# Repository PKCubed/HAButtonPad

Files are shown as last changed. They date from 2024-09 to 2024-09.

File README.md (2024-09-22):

# HAButtonPad
A board of buttons for Home Assistant

## Features I Want to Add
- Unlimitted number of switches and scenes
- Display switch names on screen when holding down the button (when holding down button, don't register it as a press)

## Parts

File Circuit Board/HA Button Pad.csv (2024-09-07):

# | Reference | Qty | Value | Footprint | DNP
1 | C1, C2, C3, C4, C5, C6, C7, C8 | 8 | C | Capacitor_SMD:C_0805_2012Metric
2 | D1, D2, D3, D4, D5, D6 | 6 | WS2812B | LED_SMD:LED_WS2812B_PLCC4_5.0x5.0mm_P3.2mm
3 | D7 | 1 | Power LED | LED_SMD:LED_0603_1608Metric
4 | D8, D9, D10, D11, D12 | 5 | D_Zener | Diode_SMD:D_0603_1608Metric
5 | DS1 | 1 | Character LCD | Display:WC1602A
6 | H1, H2, H3, H4 | 4 | MountingHole_Pad | MountingHole:MountingHole_2.5mm_Pad
7 | J1 | 1 | Barrel_Jack | Connector_BarrelJack:BarrelJack_CLIFF_FC681465S_SMT_Horizontal
8 | JP1 | 1 | Programming Jumper | Connector_PinHeader_2.54mm:PinHeader_1x02_P2.54mm_Vertical
9 | JP2 | 1 | USB Power Jumper | Connector_PinHeader_2.54mm:PinHeader_1x02_P2.54mm_Vertical
10 | JP3 | 1 | Run Program Jumper | Connector_PinHeader_2.54mm:PinHeader_1x02_P2.54mm_Vertical
11 | P1 | 1 | USB C Connector | Connector_USB:USB_C_Receptacle_GCT_USB4110
12 | Q1 | 1 | PN2222A | Package_TO_SOT_THT:TO-92_Inline
13 | R1 | 1 | Power LED Resistor | Resistor_SMD:R_0603_1608Metric
14 | R2 | 1 | SDA Pullup | Resistor_SMD:R_0603_1608Metric
15 | R3 | 1 | SCL Pullup | Resistor_SMD:R_0603_1608Metric
16 | R4 | 1 | R | Resistor_SMD:R_0603_1608Metric
17 | RV1 | 1 | Display Contrast | Potentiometer_THT:Potentiometer_ACP_CA6-H2,5_Horizontal
18 | SW1 | 1 | Button 1 | Button_Switch_THT:SW_PUSH-12mm
19 | SW2 | 1 | Button 2 | Button_Switch_THT:SW_PUSH-12mm
20 | SW3 | 1 | Button 3 | Button_Switch_THT:SW_PUSH-12mm
21 | SW4 | 1 | Button 4 | Button_Switch_THT:SW_PUSH-12mm
22 | SW5 | 1 | Bank Up | Button_Switch_THT:SW_PUSH-12mm
23 | SW6 | 1 | Bank Down | Button_Switch_THT:SW_PUSH-12mm
24 | SW7 | 1 | Program Button | Button_Switch_THT:SW_PUSH_6mm
25 | U1 | 1 | WT32-ETH01 | DevBoards:WT32-ETH01
26 | U3 | 1 | CP2102N USB TTL Converter | Package_DFN_QFN:QFN-28-1EP_5x5mm_P0.5mm_EP3.1x3.1mm
27 | U4 | 1 | Char LCD I2C Expander | Package_SO:SSOP-20_4.4x6.5mm_P0.65mm
28 | U5 | 1 | Button I2C Expander | Package_SO:SSOP-20_4.4x6.5mm_P0.65mm

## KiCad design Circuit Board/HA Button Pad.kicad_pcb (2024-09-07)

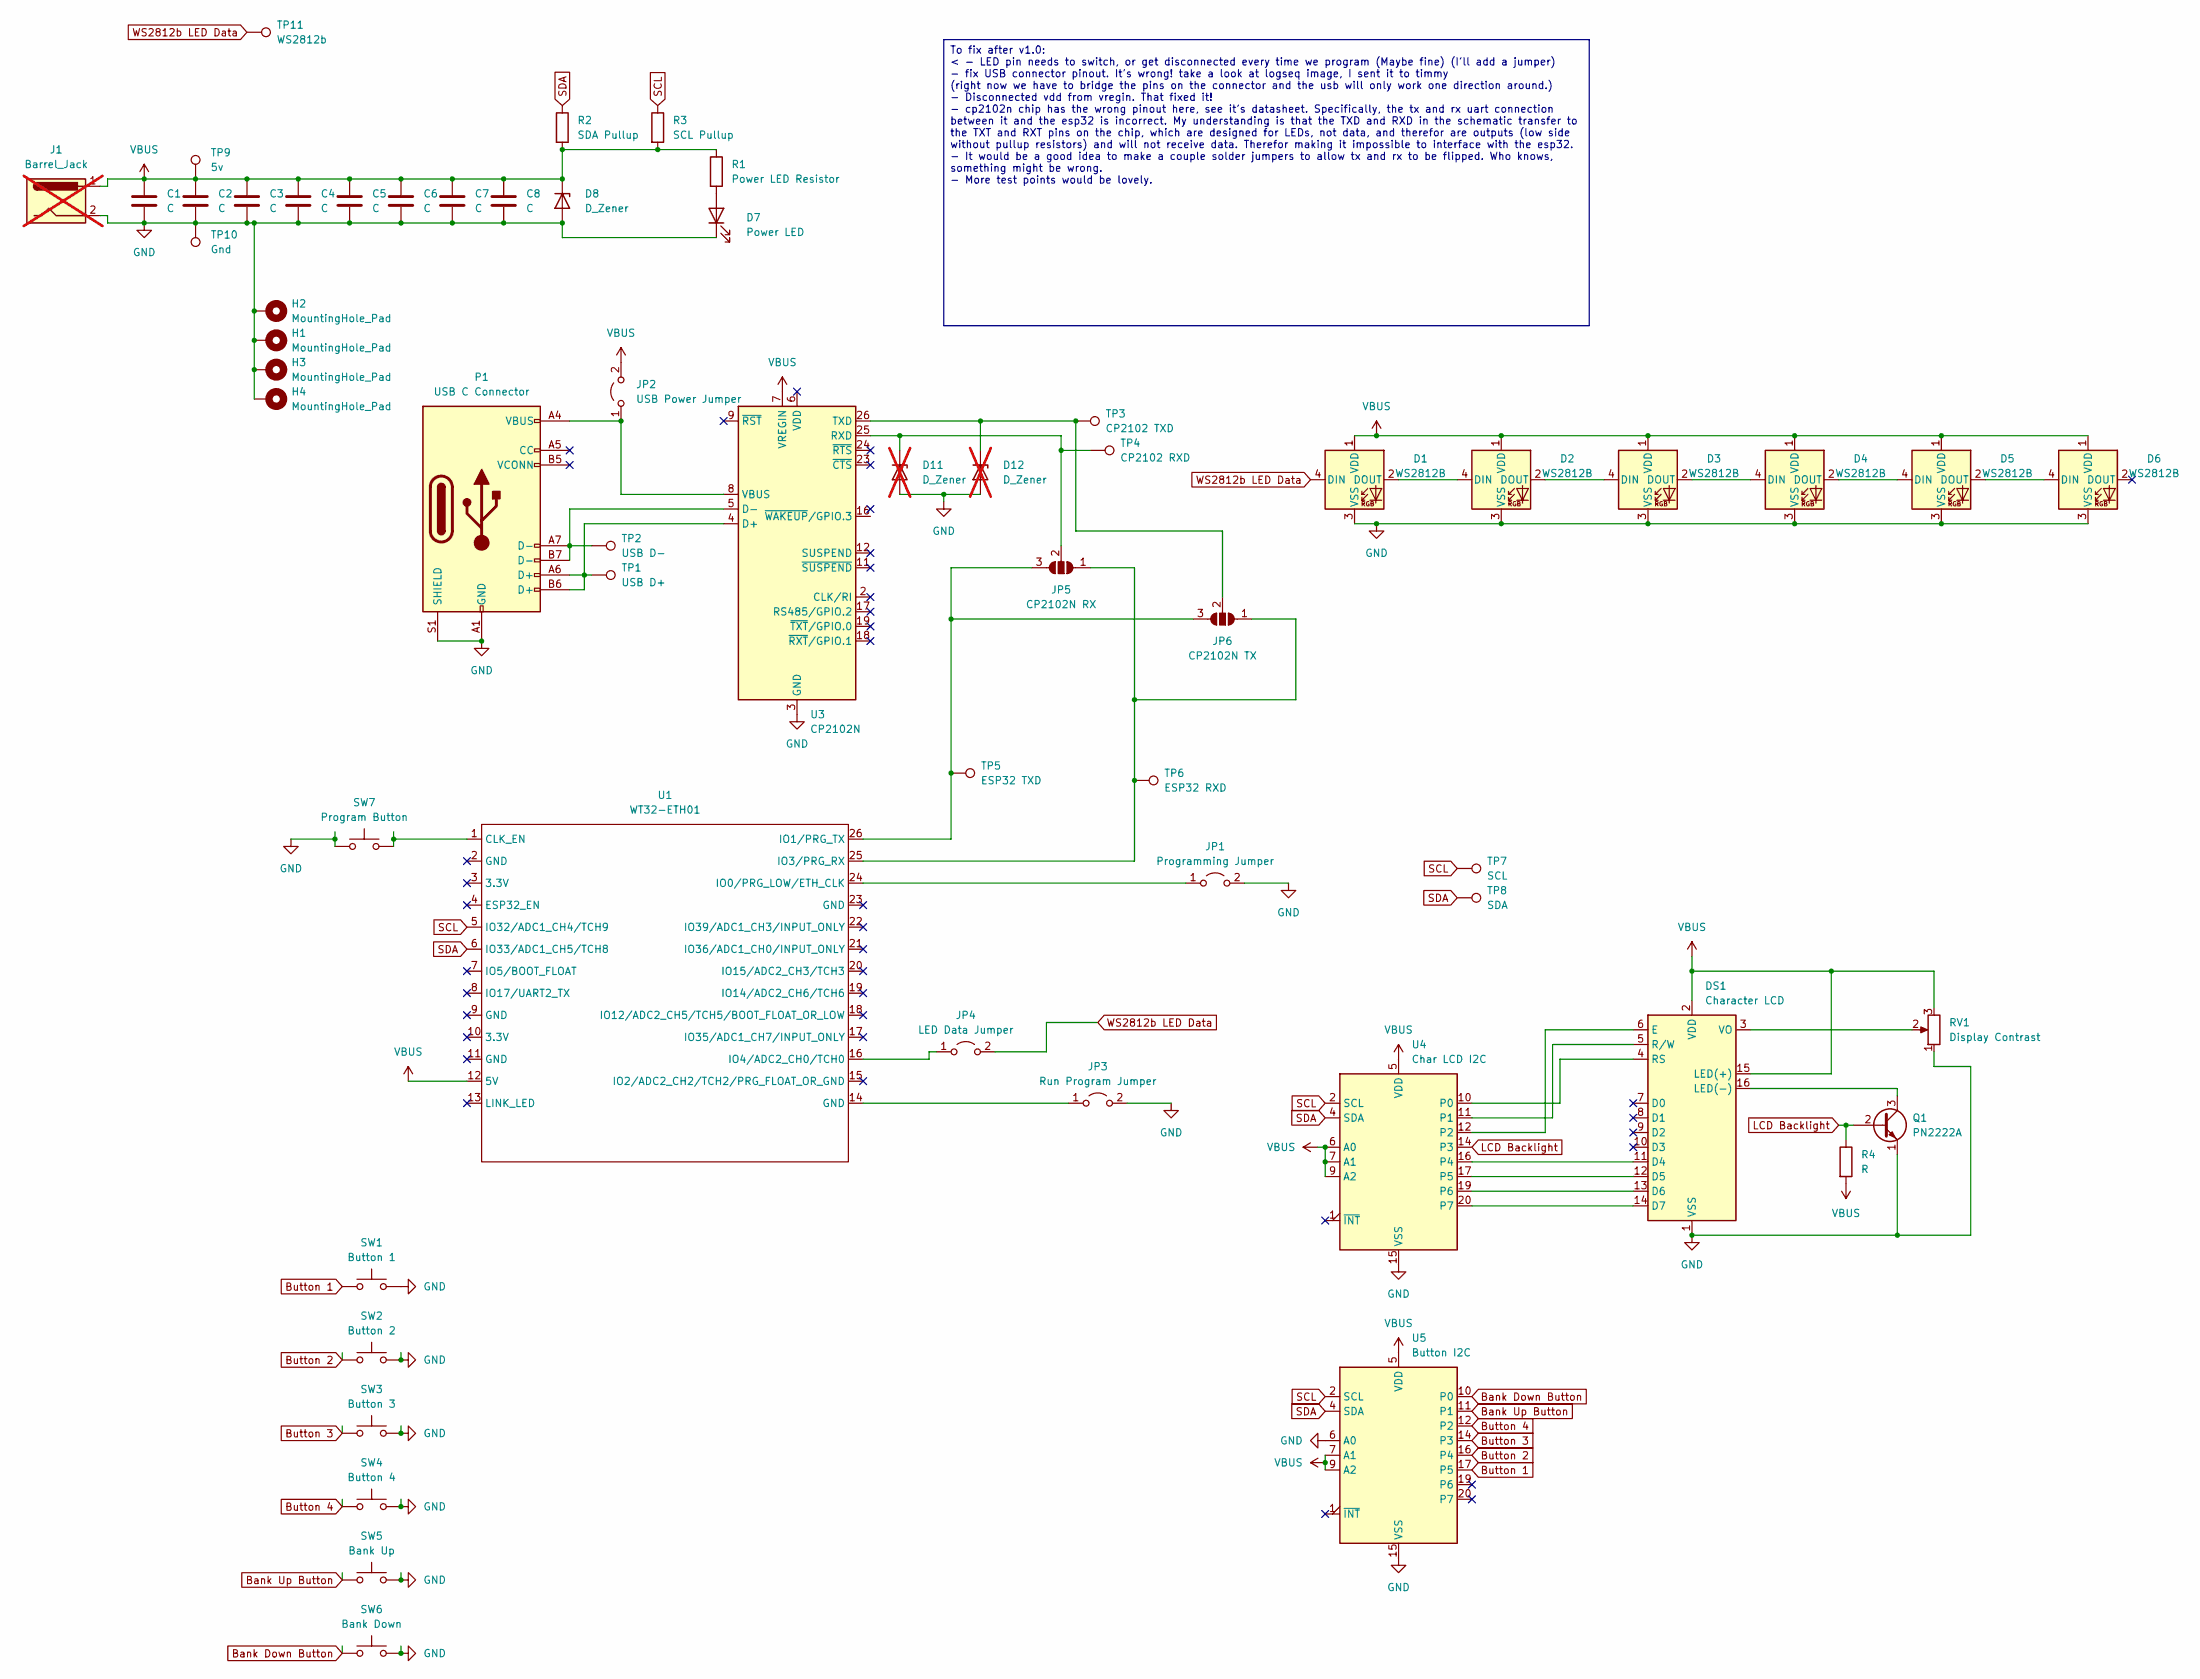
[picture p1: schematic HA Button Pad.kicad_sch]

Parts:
C1, C2, C3, C4, C5, C6, C7, C8: C; CAPC340180_88N_KEM
D1, D2, D3, D4, D5, D6: WS2812B; LED_WS2812B_PLCC4_5.0x5.0mm_P3.2mm
D7: Power LED; LED_0603_1608Metric
D8: D_Zener; SOD923_DIO
D11, D12: D_Zener; SOD923_DIO; not fitted
DS1: Character LCD; WC1602A
H1, H2, H3, H4: MountingHole_Pad; MountingHole_2.5mm_Pad
J1: Barrel_Jack; BarrelJack_CLIFF_FC681465S_SMT_Horizontal; not fitted
JP1: Programming Jumper; PinHeader_1x02_P2.54mm_Vertical
JP2: USB Power Jumper; PinHeader_1x02_P2.54mm_Vertical
JP3: Run Program Jumper; PinHeader_1x02_P2.54mm_Vertical
JP4: LED Data Jumper; PinHeader_1x02_P2.54mm_Vertical
JP5: CP2102N RX; SolderJumper-3_P2.0mm_Open_TrianglePad1.0x1.5mm_NumberLabels
JP6: CP2102N TX; SolderJumper-3_P2.0mm_Open_TrianglePad1.0x1.5mm_NumberLabels
P1: USB C Connector; USB_C_Receptacle_GCT_USB4110
Q1: PN2222A; TO-92_Inline
R1: Power LED Resistor; R_0603_1608Metric
R2: SDA Pullup; R_0603_1608Metric
R3: SCL Pullup; R_0603_1608Metric
R4: R; R_0603_1608Metric
RV1: Display Contrast; POT_3362P
SW1: Button 1; SW_PUSH-12mm
SW2: Button 2; SW_PUSH-12mm
SW3: Button 3; SW_PUSH-12mm
SW4: Button 4; SW_PUSH-12mm
SW5: Bank Up; SW_PUSH-12mm
SW6: Bank Down; SW_PUSH-12mm
SW7: Program Button; SW_PUSH_6mm
TP1: USB D+; TestPoint_Pad_D1.0mm
TP2: USB D-; TestPoint_Pad_D1.0mm
TP3: CP2102 TXD; TestPoint_Pad_D1.0mm
TP4: CP2102 RXD; TestPoint_Pad_D1.0mm
TP5: ESP32 TXD; TestPoint_Pad_D1.0mm
TP6: ESP32 RXD; TestPoint_Pad_D1.0mm
TP7: SCL; TestPoint_Pad_D1.0mm
TP8: SDA; TestPoint_Pad_D1.0mm
TP9: 5v; TestPoint_Pad_D1.0mm
TP10: Gnd; TestPoint_Pad_D1.0mm
TP11: WS2812b; TestPoint_Pad_D1.0mm
U1: WT32-ETH01
U3: CP2102N; QFN-28-1EP_5x5mm_P0.5mm_EP3.1x3.1mm
U4: Char LCD I2C; SSOP-20_4.4x6.5mm_P0.65mm
U5: Button I2C; SSOP-20_4.4x6.5mm_P0.65mm

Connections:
Bank Down Button: SW6.1, U5.10 (P0)
Bank Up Button: SW5.1, U5.11 (P1)
Button 1: SW1.1, U5.17 (P5)
Button 2: SW2.1, U5.16 (P4)
Button 3: SW3.1, U5.14 (P3)
Button 4: SW4.1, U5.12 (P2)
GND: C1.2, C2.2, C3.2, C4.2, C5.2, C6.2, C7.2, C8.2, D1.3 (VSS), D2.3 (VSS), D3.3 (VSS), D4.3 (VSS), D5.3 (VSS), D6.3 (VSS), D7.1 (K), D8.2 (A), D11.2 (A), D12.2 (A), DS1.1 (VSS), H1.1, H2.1, H3.1, H4.1, J1.2, JP1.2 (B), JP3.2 (B), P1.A1 (GND), P1.A12 (GND), P1.B1 (GND), P1.B12 (GND), P1.S1 (SHIELD), Q1.1 (E), RV1.1, SW1.2, SW2.2, SW3.2, SW4.2, SW5.2, SW6.2, SW7.1, TP10.1, U3.3 (GND), U3.12 (GND), U3.21 (GND), U4.15 (VSS), U5.6 (A0), U5.15 (VSS)
LCD Backlight: Q1.2 (B), R4.1, U4.14 (P3)
unnamed: D1.2 (DOUT), D2.4 (DIN)
unnamed: D2.2 (DOUT), D3.4 (DIN)
unnamed: D3.2 (DOUT), D4.4 (DIN)
unnamed: D4.2 (DOUT), D5.4 (DIN)
unnamed: D5.2 (DOUT), D6.4 (DIN)
unnamed: D7.2 (A), R1.2
unnamed: DS1.11 (D4), U4.16 (P4)
unnamed: DS1.12 (D5), U4.17 (P5)
unnamed: DS1.13 (D6), U4.19 (P6)
unnamed: DS1.14 (D7), U4.20 (P7)
unnamed: DS1.6 (E), U4.12 (P2)
unnamed: DS1.16 (LED(-)), Q1.3 (C)
unnamed: DS1.4 (RS), U4.10 (P0)
unnamed: DS1.5 (R/W), U4.11 (P1)
unnamed: DS1.3 (VO), RV1.2
unnamed: JP1.1 (A), U1.24 (IO0/PRG_LOW/ETH_CLK)
unnamed: JP2.1 (A), P1.A4 (VBUS), P1.A9 (VBUS), P1.B4 (VBUS), P1.B9 (VBUS), U3.8 (VBUS)
unnamed: JP3.1 (A), U1.14 (GND)
unnamed: JP4.1 (A), U1.16 (IO4/ADC2_CH0/TCH0)
unnamed: JP5.1 (A), JP6.1 (A), TP6.1, U1.25 (IO3/PRG_RX)
unnamed: JP5.3 (B), JP6.3 (B), TP5.1, U1.26 (IO1/PRG_TX)
unnamed: D11.1 (K), JP5.2 (C), TP4.1, U3.25 (RXD)
unnamed: D12.1 (K), JP6.2 (C), TP3.1, U3.26 (TXD)
unnamed: SW7.2, U1.1 (CLK_EN)
unnamed: P1.A6 (D+), P1.B6 (D+), TP1.1, U3.4 (D+)
unnamed: P1.A7 (D-), P1.B7 (D-), TP2.1, U3.5 (D-)
SCL: R3.1, TP7.1, U1.5 (IO32/ADC1_CH4/TCH9), U4.2 (SCL), U5.2 (SCL)
SDA: R2.1, TP8.1, U1.6 (IO33/ADC1_CH5/TCH8), U4.4 (SDA), U5.4 (SDA)
VBUS: C1.1, C2.1, C3.1, C4.1, C5.1, C6.1, C7.1, C8.1, D1.1 (VDD), D2.1 (VDD), D3.1 (VDD), D4.1 (VDD), D5.1 (VDD), D6.1 (VDD), D8.1 (K), DS1.2 (VDD), DS1.15 (LED(+)), J1.1, JP2.2 (B), R1.1, R2.2, R3.2, R4.2, RV1.3, TP9.1, U1.12 (5V), U3.7 (VREGIN), U4.5 (VDD), U4.6 (A0), U4.7 (A1), U4.9 (A2), U5.5 (VDD), U5.7 (A1), U5.9 (A2)
WS2812b LED Data: D1.4 (DIN), JP4.2 (B), TP11.1

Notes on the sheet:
To fix after v1.0: < - LED pin needs to switch, or get disconnected every time we program (Maybe fine) (I'll add a jumper) - fix USB connector pinout. It's wrong! take a look at logseq image, I sent it to timmy (right now we have to bridge the pins on the connector and the usb will only work one di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

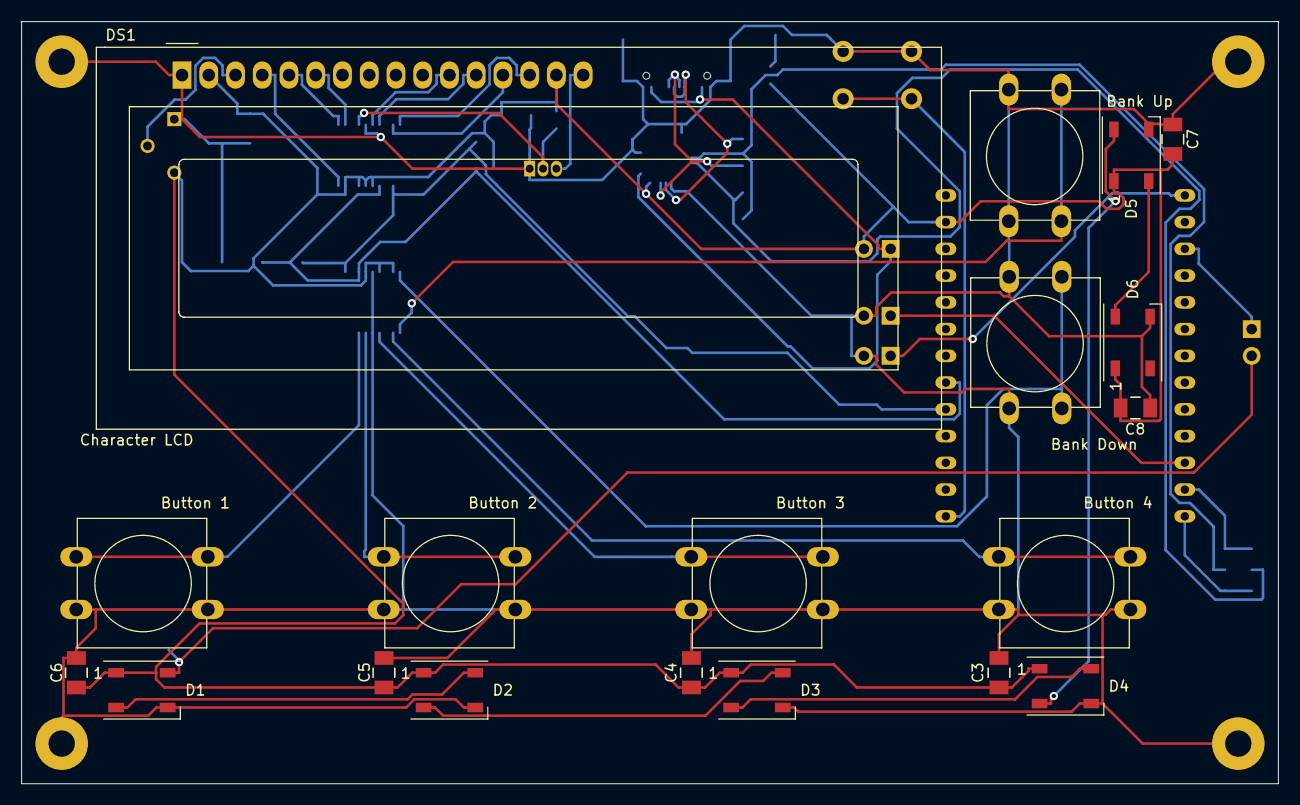
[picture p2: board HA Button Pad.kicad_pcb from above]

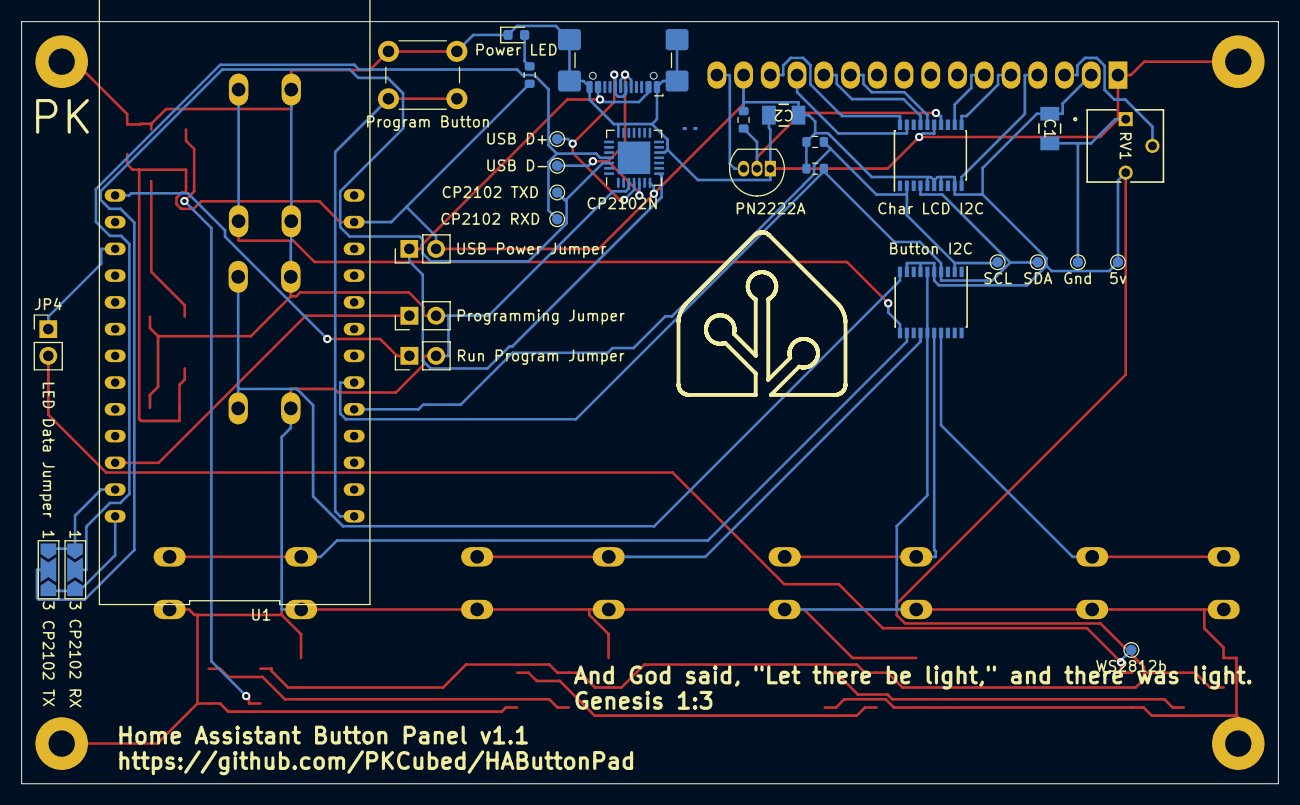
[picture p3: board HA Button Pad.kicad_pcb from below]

Board: 2 copper layers, 119.4 x 72.4 mm, 54 parts (31 on the bottom side), 38 nets.

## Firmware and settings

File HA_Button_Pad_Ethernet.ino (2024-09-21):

// Initiallization and Configuration
  const char* version = "v1.1";
  // WT32-ETH01 Specific Ethernet Libraries
    #define DEBUG_ETHERNET_WEBSERVER_PORT       Serial
    #define _ETHERNET_WEBSERVER_LOGLEVEL_       3
    #include "EthWebServer.h" // This library includes WiFi.h and WebServer.h
    WebServer server(80); // Initialize the Web Server at port 80 (This is both ethernet and wifi)
  // I2C
    #include "Wire.h" // The I2C Library
    int i2c_sda = 32;
    int i2c_scl = 33;
    // PCF8574 for Button Input
      #include <Adafruit_PCF8574.h> // Include the 8574 chip library to read input from the buttons. This same chip is used to output data to the character display with the LiquidCrystal_I2C.h library.
      Adafruit_PCF8574 buttoni2c;
    // PCF8574 for Character LCD
      #include <LiquidCrystal_I2C.h> // For communication with the 16x2 char display via the 8574 chip
      LiquidCrystal_I2C lcd(0x27, 16, 2); // Initialize the LCD

  // ws2812b
    #include <FastLED.h> // For outputing data to the ws2812b LEDs
    #define NUM_LEDS 6
    #define DATA_PIN 4 // ws2812b LED data pin
    CRGB leds[NUM_LEDS]; // Create an array with each led object

  // WiFi
    //#include <WiFi.h> // for WiFi
    
    //#include <WiFiClient.h>
    //#include <WebServer.h>

    String ssid; // WiFi SSID
    String password; // WiFi Password

  // MQTT
    #include <PubSubClient.h> // For MQTT
    String mqtt_server = "10.0.2.5"; // Define the MQTT broker ip address here (this will later be configured with the web ui and be stored in memory)
    WiFiClient mqttClient; // Create the Wifi Client object (This covers both ethernet and wifi)

    PubSubClient client(mqttClient); // mqtt client object

    String mqttSwitch = "buttonpanels/switch"; // this is the MQTT address of each switch. We append a 0-∞ at the end, ex. "buttonpanels/switch5"
    String mqttScene = "buttonpanels/scene"; // this is the MQTT address of each scene selection. We append a 0-∞ at the end, ex. "buttonpanels/switch5"

    String mqttuser = "mqtt"; // MQTT Username
    String mqttpw = "12345678"; // MQTT Password
    String mqttdevicename = "HAButtonPanel"; // Device name. This is not just for MQTT, but we use this as the overall device name.

  // Update
    #include <Update.h>
  // Preferences
    // This library allows us to save data to the ESP32's non volatile memory so it persists between resets and power loss.
    #include <Preferences.h>
    Preferences preferences;

  // Buttons
    const int debounceTime = 100; // The duration in milliseconds that a button will virtually stay pressed after it has been physically pressed. This removes any bounces on the rising edge. 
    // Pins
      const int b1 = 5, b2 = 4, b3 = 3, b4 = 2, b5 = 0, b6 = 1; // Buttons (Left --> Top)   These are the pins of the physical buttons on the 8574 chip.

  // Configuration
    const char* bankNames[8] = { // These are the names of the banks that show up on the first row of the LCD screen.
      "Houselights   ",
      "Valances      ",
      "Stage Lights  ",
      "ChristmasLghts",
      "Audio Systems ",
      "Video Systems ",
      "Scenes A      ", // Radio Buttons
      "Scenes B      "  // Radio Buttons
      };
  
  // Web Pages
    // Root Site Definitions
      // I have to break these up so we can put variables in between. There has to be a cleaner solution. Maybe we can stuff this stuff into an array?
      const String rootSite[] = {
        F("<html>\
        <head>\
        <title>"),
        F("</title>\
        <style>\
        body { background-color: #000000; font-family: Arial, Helvetica, Sans-Serif; Color: #3344ff; }\
        </style>\
        </head>\
        <body>\
        </form>\
        <h1>Settings</h1><br>\
        <form method=\"post\" enctype=\"application/x-www-form-urlencoded\" action=\"/\">\
        <p>Device Name (Requires reboot to take effect)</p>\
        <input type=\"text\" name=\"name\" value=\""),
        F("\"><br>\
        <p>WiFi SSID</p>\
        <input type=\"text\" name=\"ssid\" value=\""),
        F("\"><br>\
        <p>WiFi Password (Leave empty for no change)</p>\
        <input type=\"password\" name=\"wifi_pw\" value=\"\"\>\
        <br>\
        <input type=\"submit\" value=\"Submit\">\
        </form>\
        <a href=\"update\">OTA Update</a>\
        <a href=\"reboot\">Reboot</a>\
        </body>\
        </html>")
      };

      // Update Page
        const char* updateSite = 
          "<script src='https://ajax.googleapis.com/ajax/libs/jquery/3.2.1/jquery.min.js'></script>"
          "<form method='POST' action='#' enctype='multipart/form-data' id='upload_form'>"
            "<input type='file' name='update'>"
                  "<input type='submit' value='Update'>"
              "</form>"
          "<div id='prg'>progress: 0%</div>"
          "<script>"
            "$('form').submit(function(e){"
            "e.preventDefault();"
            "var form = $('#upload_form')[0];"
            "var data = new FormData(form);"
            " $.ajax({"
            "url: '/update',"
            "type: 'POST',"
            "data: data,"
            "contentType: false,"
            "processData:false,"
            "xhr: function() {"
            "var xhr = new window.XMLHttpRequest();"
            "xhr.upload.addEventListener('progress', function(evt) {"
            "if (evt.lengthComputable) {"
            "var per = evt.loaded / evt.total;"
            "$('#prg').html('progress: ' + Math.round(per*100) + '%');"
            "}"
            "}, false);"
            "return xhr;"
            "},"
            "success:function(d, s) {"
            "console.log('success!')"
          "},"
          "error: function (a, b, c) {"
          "}"
          "});"
          "});"
          "</script>";

  // initiallization of blank variables
    int bank = 0; // The bank is what set of buttons/switches we are looking at. We have 4 physical buttons, and we can cycle through the banks to control many different switches with those 4 buttons. For example, bank 0 shows switches 0-3 on the buttons. bank 1 shows switches 4-7 on the buttons.
    int lastBank = 0; // to detect changes in banks.
    int switches[8][4] = {{0,0,0,0}, {0,0,0,0}, {0,0,0,0}, {0,0,0,0}, {0,0,0,0}, {0,0,0,0}}; // These are the states of the switches. Eventually we need to be able to set this up to be an infinite number of switches configured in the web interface.
    int scenes[1] = {0}; // 0-7    This is the value of each scene selection. right now, we just have one scene selection. Eventually, we need to be able to set this up to be an infinite number of scene selections configured in the web interface.
    int buttonStates[] = {0,0,0,0,0,0}; // these are the states of the physical buttons. there are 6 buttons, 4 for the switches, and 2 to select banks. They also have other functions.
    int buttonLastStates[] = {0,0,0,0,0,0}; // To detect rising and falling edges of the button presses
    int buttonTimes[] = {0,0,0,0,0,0}; // To allow for software debouncing of the buttons. We basically extend the rising edge to be as long as the debounceTime if not longer.
    IPAddress blankIP(0, 0, 0, 0); // Create a blank IP address as a "reference" to compare to in order to see if we got an IP address.

    
// Web Page Functions
  void handleRoot() // This function runs when someone navigates to the root page of the web interface.
  {
    if (server.method() != HTTP_POST) // If someone is sending data via GET
    {
      //server.send(200, F("text/html"), "Hello World - GET RECEIVED");
      Serial.println("Get Request Received");
      Serial.println(mqttdevicename);
    }
    else // If someone is just requesting via POST
    {
      //String message = F("POST form was:\n");
      
      preferences.begin("habuttonpad", false); // false = read/write, true = read only

      for (uint8_t i = 0; i < server.args(); i++)
      {
        //message += " " + server.argName(i) + ": " + server.arg(i) + "\n";
        if (server.argName(i) == "name") {
          preferences.putString("name", server.arg(i));
          Serial.println(server.arg(i));
          //mqttdevicename = server.arg(i);
        } else if (server.argName(i) == "ssid") {
          preferences.putString("wifi_ssid", server.arg(i));
          Serial.println(server.arg(i));
          ssid = server.arg(i);
        } else if (server.argName(i) == "wifi_pw") {
          if (server.arg(i) != String("")) {
            preferences.putString("wifi_pw", server.arg(i));
            Serial.println(server.arg(i));
            password = server.arg(i);
          }
        }
      }

      preferences.end();

      //server.send(200, F("text/plain"), mqttdevicename);
    }
    server.send(200, F("text/html"), rootSite[0]+mqttdevicename+rootSite[1]+mqttdevicename+rootSite[2]+ssid+rootSite[3]);
  }

  void handleNotFound() // When someone navigates to a page that does not exist.
  {
    String message = F("File Not Found\n\n");
    
    message += F("URI: ");
    message += server.uri();
    message += F("\nMethod: ");
    message += (server.method() == HTTP_GET) ? F("GET") : F("POST");
    message += F("\nArguments: ");
    message += server.args();
    message += F("\n");
    
    for (uint8_t i = 0; i < server.args(); i++)
    {
      message += " " + server.argName(i) + ": " + server.arg(i) + "\n";
    }
    
    server.send(404, F("text/plain"), message);
  }

// Functions
  void mqttconnect() { // This function connects mqtt
    lcd.clear();
    lcd.print("MQTT Connecting");
    // Loop until we're reconnected
    int counter = 0;
    while (!client.connected()) {
      if (counter == 5) {
        Serial.println("Restarting...");
        lcd.clear();
        lcd.print("Failed connection");
        lcd.setCursor(0,1);
        lcd.print("Restarting...");
        delay(1500);
        
        ESP.restart(); // Restart everything
      }
      counter += 1;
      Serial.print("Attempting MQTT connection...");
      // Attempt to connect

      client.disconnect();
      client.setClient(mqttClient);

      delay(1000);

      if (client.connect(mqttdevicename.c_str(), mqttuser.c_str(), mqttpw.c_str())) {
        Serial.println("connected");
        lcd.clear();
        lcd.print("MQTT Connected");
        break;
      } else {
        lcd.clear();
        lcd.print("Failed connection");
        lcd.setCursor(0,1);
        lcd.print("Try again in 2s");
        Serial.print("failed, rc=");
        Serial.print(client.state());
        Serial.println(" trying again in 2 seconds");
        delay(2000);
      }
    }
    Serial.println("Subscribing to MQTT topics");
    for (int i=0;i<=24;i++) {
      client.subscribe((mqttSwitch + String(i)).c_str());
    }
    client.subscribe((mqttScene + String(0)).c_str());
    showbank();
    lastBank = bank;
  }

  void mqttcallback(char* topic, byte* payload, unsigned int length) { // This function runs when a topic we've subscribed to has a new message for us.
    //Serial.print("Message arrived [");
    //Serial.print(topic);
    //Serial.print("] ");
    for (int i=0;i<length;i++) {
      Serial.print((char)payload[i]);
    }
    Serial.println();
    if (String(topic).startsWith(mqttSwitch)) {
      switches[String(topic).substring(mqttSwitch.length()).toInt()/4][String(topic).substring(mqttSwitch.length()).toInt()%4] = (char)payload[0] - '0';
    } if (String(topic).startsWith(mqttScene)) {

      scenes[0] = (char)payload[0] - '0';
    }
  }

  void showbank() { // We run this function to show the current bank name on the LCD screen.
    lcd.clear();
    lcd.print(bank+1);
    lcd.print(".");
    lcd.print(bankNames[bank]);
  }

  void wificonnect() {
    Serial.println("Connecting to WiFi...");

    WiFi.mode(WIFI_STA);
    WiFi.disconnect();
    WiFi.begin(ssid.c_str(), password.c_str());
    if (ETH.localIP()==blankIP) { // If Ethernet is Connected -  This compares the Ethernet IP with 0.0.0.0 to see if we have an IP address on the Ethernet interface. If not, ETH.localIP() will return 0.0.0.0 and we can catch that.
      // Ethernet is NOT connected
      Serial.println("Ethernet is NOT connected, so WiFi is required now.");
      lcd.clear();
      lcd.print("Connecting WiFi");
      lcd.setCursor(0,1);
      lcd.print("SSID: ");
      lcd.print(ssid.c_str());
      while (WiFi.status() != WL_CONNECTED) {
        delay(10);
        Serial.print(".");
        if (millis() > 18000) { // If we have been waiting toooooo long
          Serial.println("WiFi Connection Timeout. Rebooting.")
          lcd.clear();
          lcd.print("WiFi Failure");
          lcd.setCursor(0,1);
          lcd.print("Rebooting in 2s");
          delay(2000);
          ESP.restart(); // Restart everything
        }
      }
      Serial.println("WiFi Connection Successful. IP Address:");
      Serial.println(WiFi.localIP());
      lcd.clear();
      lcd.print("WiFi Successful");
      lcd.setCursor(0,1);
      lcd.print(WiFi.localIP());
    } else { // If Ethernet IS connected, we don't need to worry about making sure that the WiFi connection is successful.
      Serial.println("Ethernet IS connected, so WiFi is not required, and we will not reboot upon an unsuccessful connection. Nothing will print on the screen, no delays either.");
    }
  }
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
void loop() {
  // Verify Connections
    if (WiFi.status() == WL_CONNECTED) { // If WiFi is connected
      if (!client.connected()) { // If MQTT is NOT connected
        Serial.println("Detected MQTT disconnection. Attempting reconnection.");
        mqttconnect();
      }
    } else {
      if (ETH.localIP()==blankIP) { // If WIFI is NOT connected and Ethernet is NOT connected
        Serial.println("Detected WiFi disconnection, attempting reconnection.");
        wificonnect();
      }
    }

  // Loop Functions
    client.loop(); // MQTT Loop Function
    server.handleClient(); // WebServer Loop Function

  if (bank != lastBank) { // Detect changes in the bank variable
    showbank(); // If we switched banks, display that new bank.
    lastBank = bank;
  }

  // Update LEDs
    if (bank <= 5) {
      if (switches[bank][0]) {
        leds[0] = CRGB(0, 255, 0);
      } else {
        leds[0] = CRGB(20,0,0);
      }
      if (switches[bank][1]) {
        leds[1] = CRGB(0, 255, 0);
      } else {
        leds[1] = CRGB(20,0,0);
      }
      if (switches[bank][2]) {
        leds[2] = CRGB(0, 255, 0);
      } else {
        leds[2] = CRGB(20,0,0);
      }
      if (switches[bank][3]) {
        leds[3] = CRGB(0, 255, 0);
      } else {
        leds[3] = CRGB(20,0,0);
      }
    } else if (bank == 6) {
      if (scenes[0] == 0) {
        leds[0] = CRGB(0, 30, 255);
      } else {
        leds[0] = CRGB(0,0,10);
      }
      if (scenes[0] == 1) {
        leds[1] = CRGB(0, 30, 255);
      } else {
        leds[1] = CRGB(0,0,10);
      }
      if (scenes[0] == 2) {
        leds[2] = CRGB(0, 30, 255);
      } else {
        leds[2] = CRGB(0,0,10);
      }
      if (scenes[0] == 3) {
        leds[3] = CRGB(0, 30, 255);
      } else {
        leds[3] = CRGB(0,0,10);
      }
    } else if (bank == 7) {
      if (scenes[0] == 4) {
        leds[0] = CRGB(0, 30, 255);
      } else {
        leds[0] = CRGB(0,0,10);
      }
      if (scenes[0] == 5) {
        leds[1] = CRGB(0, 30, 255);
      } else {
        leds[1] = CRGB(0,0,10);
      }
      if (scenes[0] == 6) {
        leds[2] = CRGB(0, 30, 255);
      } else {
        leds[2] = CRGB(0,0,10);
      }
      if (scenes[0] == 7) {
        leds[3] = CRGB(0, 30, 255);
      } else {
        leds[3] = CRGB(0,0,10);
      }
    }
    FastLED.show();


  // Read Button Input
    if (!buttoni2c.digitalRead(b1)) {
      buttonStates[0] = 1;
      buttonTimes[0] = millis();
    } else if (millis() >= buttonTimes[0] + debounceTime) {
      buttonStates[0] = 0;
    }
    if (!buttoni2c.digitalRead(b2)) {
      buttonStates[1] = 1;
      buttonTimes[1] = millis();
    } else if (millis() >= buttonTimes[1] + debounceTime) {
      buttonStates[1] = 0;
    }
    if (!buttoni2c.digitalRead(b3)) {
      buttonStates[2] = 1;
      buttonTimes[2] = millis();
    } else if (millis() >= buttonTimes[2] + debounceTime) {
      buttonStates[2] = 0;
    }
    if (!buttoni2c.digitalRead(b4)) {
      buttonStates[3] = 1;
      buttonTimes[3] = millis();
    } else if (millis() >= buttonTimes[3] + debounceTime) {
      buttonStates[3] = 0;
    }
    if (!buttoni2c.digitalRead(b5)) {
      buttonStates[4] = 1;
      buttonTimes[4] = millis();
    } else if (millis() >= buttonTimes[4] + debounceTime) {
      buttonStates[4] = 0;
    }
    if (!buttoni2c.digitalRead(b6)) {
      buttonStates[5] = 1;
      buttonTimes[5] = millis();
    } else if (millis() >= buttonTimes[5] + debounceTime) {
      buttonStates[5] = 0;
    }


  // Process Button Input
    if (buttonStates[0] && !buttonLastStates[0]) { // Detect rising edge
      buttonLastStates[0] = 1;
      if (bank <= 5) {
        switches[bank][0] = !switches[bank][0];
        if (switches[bank][0]) {
          client.publish((mqttSwitch+String(bank*4+0)).c_str(), "1", true);
        } else {
          client.publish((mqttSwitch+String(bank*4+0)).c_str(), "0", true);
        }
      } else  {
        scenes[0] = (bank-6)*4;
        client.publish(("hapanel1/scene0"), String(scenes[0]).c_str(), true);
        Serial.print(scenes[0]);
      }
    } if (!buttonStates[0] && buttonLastStates[0]) { // Detect falling edge
      buttonLastStates[0] = 0;
    }
    if (buttonStates[1] && !buttonLastStates[1]) { // Detect rising edge
      buttonLastStates[1] = 1;
      if (bank <= 5) {
        switches[bank][1] = !switches[bank][1];
        if (switches[bank][1]) {
          client.publish((mqttSwitch+String(bank*4+1)).c_str(), "1", true);
        } else {
          client.publish((mqttSwitch+String(bank*4+1)).c_str(), "0", true);
        }
      } else {
        scenes[0] = (bank-6)*4+1;
        client.publish(("hapanel1/scene0"), String(scenes[0]).c_str(), true);
        Serial.print(scenes[0]);
      }
    } if (!buttonStates[1] && buttonLastStates[1]) { // Detect falling edge
      buttonLastStates[1] = 0;
    }
    if (buttonStates[2] && !buttonLastStates[2]) { // Detect rising edge
      buttonLastStates[2] = 1;
      if (bank <= 5) {
        switches[bank][2] = !switches[bank][2];
        if (switches[bank][2]) {
          client.publish((mqttSwitch+String(bank*4+2)).c_str(), "1", true);
        } else {
          client.publish((mqttSwitch+String(bank*4+2)).c_str(), "0", true);
        }
      } else {
        scenes[0] = (bank-6)*4+2;
        client.publish(("hapanel1/scene0"), String(scenes[0]).c_str(), true);
        Serial.print(scenes[0]);
      }
    } if (!buttonStates[2] && buttonLastStates[2]) { // Detect falling edge
      buttonLastStates[2] = 0;
    }
    if (buttonStates[3] && !buttonLastStates[3]) { // Detect rising edge
      buttonLastStates[3] = 1;
      if (bank <= 5) {
        switches[bank][3] = !switches[bank][3];
        if (switches[bank][3]) {
          client.publish((mqttSwitch+String(bank*4+3)).c_str(), "1", true);
        } else {
          client.publish((mqttSwitch+String(bank*4+3)).c_str(), "0", true);
        }
      } else {
        scenes[0] = (bank-6)*4+3;
        client.publish(("hapanel1/scene0"), String(scenes[0]).c_str(), true);
        Serial.print(scenes[0]);
      }
    } if (!buttonStates[3] && buttonLastStates[3]) { // Detect falling edge
      buttonLastStates[3] = 0;
    }
    if (buttonStates[4] && !buttonLastStates[4]) { // Detect rising edge
      Serial.println("Button 5 Pressed");
      buttonLastStates[4] = 1;
      bank--;
      if (bank <= 0) {
        bank = 0;
      }
      Serial.println(bank);
    } if (!buttonStates[4] && buttonLastStates[4]) { // Detect falling edge
      buttonLastStates[4] = 0;
    }
    if (buttonStates[5] && !buttonLastStates[5]) { // Detect rising edge
      Serial.println("Button 6 Pressed");
      buttonLastStates[5] = 1;
      bank++;
      if (bank >= 7) {
        bank = 7;
      }
      Serial.println(bank);
    } if (!buttonStates[5] && buttonLastStates[5]) { // Detect falling edge
      buttonLastStates[5] = 0;
    }
}

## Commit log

2024-06-23 v1.1 Added I2C Display Version
2024-09-21 Delete ButtonPad 4-button 16x2 LCD.FCStd
    This was for the original prototype, which is now not in use. I created a new design with a circuit board.
    [ButtonPad 4-button 16x2 LCD.FCStd]
2024-09-21 Delete HA_Button_Pad_I2C.ino
    We only have the ethernet board now. This is unused.
2024-09-21 Delete HA_Button_Pad.ino
    Deleted this because we only have the ethernet board now
2025-08-27 Added basic motor test
